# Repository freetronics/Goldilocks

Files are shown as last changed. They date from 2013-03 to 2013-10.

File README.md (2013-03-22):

Freetronics Goldilocks
======================
Copyright 2013 Freetronics Pty Ltd  
Freetronics site:  www.freetronics.com  
Freetronics email: info@freetronics.com  

Add Description

Features:

 * Prototyping area
 * LEDs visible on the edge
 * Mini-USB Connector
 * Overlay guide where you need it (both top and bottom)
 * D13 pin works for everything
 * Mounting holes and power pads
 * All connections in the same place

You can view more online at:

  http://www.freetronics.com/goldilocks

The "docs" folder within this repository includes a handy copy of the
schematic in PDF format, images of the pcb, and our Getting Started
guide that ships with each board.

INSTALLATION
------------
The design is saved as an EAGLE project. EAGLE PCB design software is
available from www.cadsoftusa.com free for non-commercial use. To use
this project download it and place the directory containing these files
into the "eagle" directory on your computer. Then open EAGLE and
navigate to Projects -> eagle -> Goldilocks.

DISTRIBUTION
------------
The specific terms of distribution of this project are governed by the
license referenced below.

LICENSE
-------
Licensed under the TAPR Open Hardware License (www.tapr.org/OHL).
The "license" folder within this repository also contains a copy of
this license in plain text format.

CREDITS
-------
The Eleven was designed Jonathan Oxer (jon@freetronics.com) in
collaboration with Phillip Stevens.

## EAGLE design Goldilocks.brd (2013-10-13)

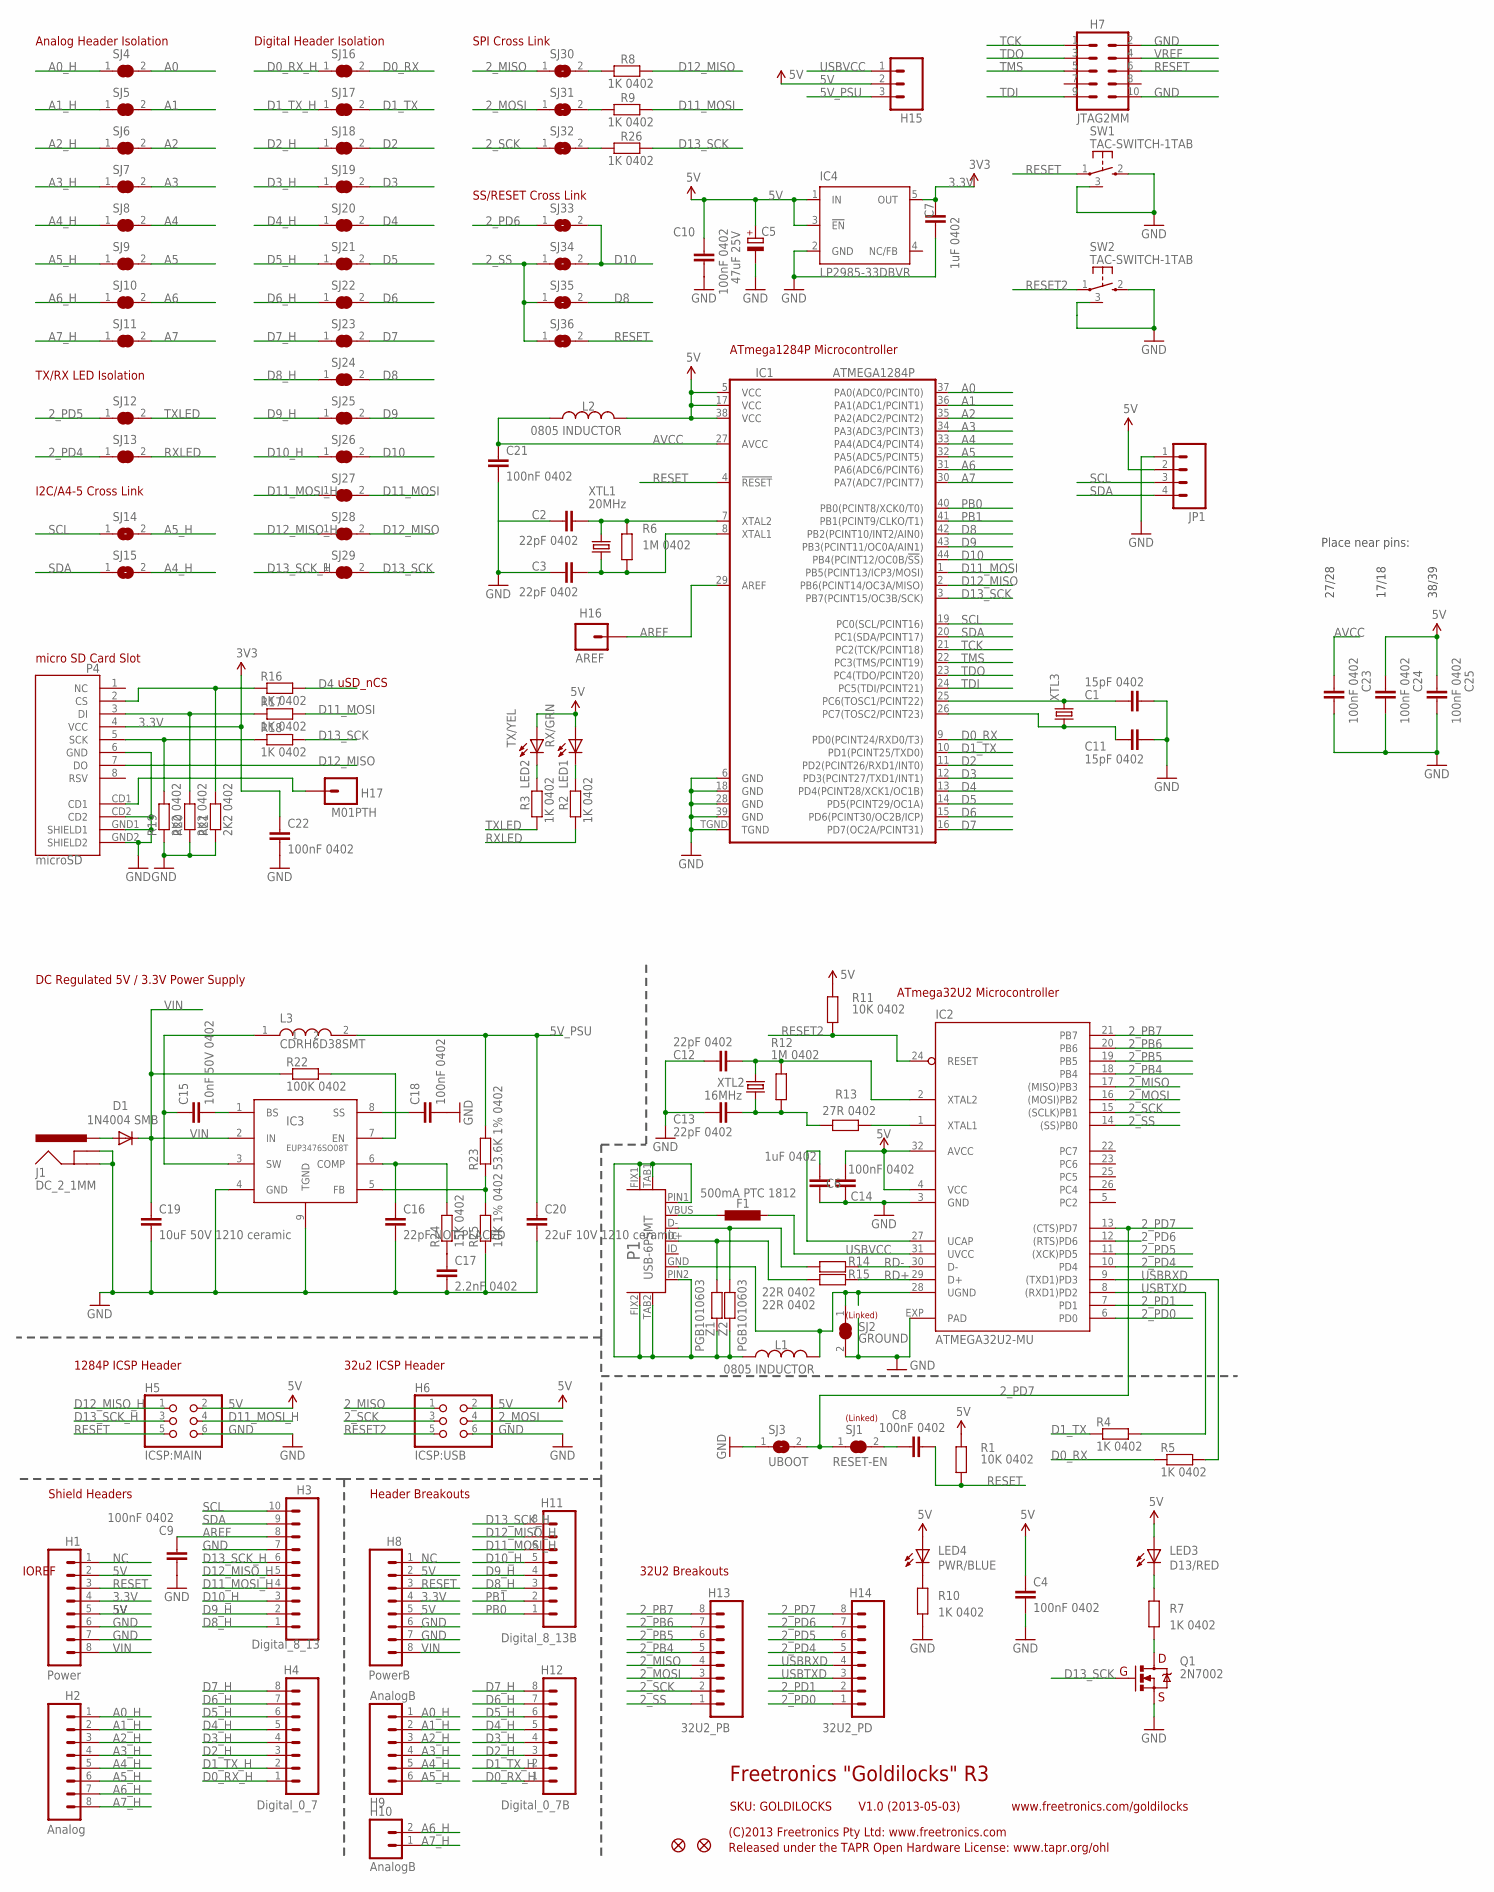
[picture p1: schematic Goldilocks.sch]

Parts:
C1, C11: 15pF 0402; 0402C
C2, C3, C12, C13: 22pF 0402; 0402C
C4, C8, C9, C10, C14, C18, C21, C22, C23, C24, C25: 100nF 0402; 0402C
C5: 47uF 25V; PANASONIC_D
C6, C7: 1uF 0402; 0402C
C15: 10nF 50V 0402; 0402C
C16: 22pF NOT PLACED; 0402C
C17: 2.2nF 0402; 0402C
C19: 10uF 50V 1210 ceramic; C1210
C20: 22uF 10V 1210 ceramic; C1210
D1: 1N4004 SMB; SMB-DIODE
F1: 500mA PTC 1812; L1812
H1: Power; 1X08
H2: Analog; 1X08
H3: Digital_8_13; 1X10
H4: Digital_0_7; 1X08
H5: ICSP:MAIN; 2X03
H6: ICSP:USB; 2X03
H7: JTAG2MM; SAMTEC-TMM-DOUBLE
H8: PowerB; 1X08
H9: AnalogB; 1X06
H10: AnalogB; 1X02
H11: Digital_8_13B; 1X08
H12: Digital_0_7B; 1X08
H13: 32U2_PB; 1X08
H14: 32U2_PD; 1X08
H15: M03PTH; 1X03
H16: AREF; 1X01
H17: M01PTH; 1X01
IC1: ATMEGA1284P; QFN-44M1
IC2: ATMEGA32U2-MU; ATMEL_QFN32
IC3: EUP3476SO08T; SO08T
IC4: LP2985-33DBVR; TEXAS_SOT23-DBV
J1: DC_2_1MM; POWER_JACK_PTH
JP1: M04PTH; 1X04
L1, L2: 0805 INDUCTOR; 0805-LARGE
L3: CDRH6D38SMT; CDRH
LED1: RX/GRN; LED-0402
LED2: TX/YEL; LED-0402
LED3: D13/RED; LED-0402
LED4: PWR/BLUE; LED-0402
P1: USB-6PSMT; USB-MICROB-MB05PMXX
P4: microSD; MICRO-SD-SOCKET-PP
Q1: 2N7002; SOT23-3
R1, R11: 10K 0402; 0402
R2, R3, R4, R5, R7, R8, R9, R10, R16, R17, R18, R26: 1K 0402; 0402
R6, R12: 1M 0402; 0402
R13: 27R 0402; 0402
R14, R15: 22R 0402; 0402
R19, R20, R21: 2K2 0402; 0402
R22: 100K 0402; 0402
R23: 53.6K 1% 0402; 0402
R24: 15K 0402; 0402
R25: 10K 1% 0402; 0402
SJ1: RESET-EN; SJC
SJ2: GROUND; SJC
SJ3: UBOOT; SJ
SJ4, SJ5, SJ6, SJ7, SJ8, SJ9, SJ10, SJ11, SJ12, SJ13, SJ16, SJ17, SJ18, SJ19, SJ20, SJ21, SJ22, SJ23, SJ24, SJ25, SJ26, SJ27, SJ28, SJ29: SJC0402; 0402SJC
SJ14, SJ15: SJ
SJ30: MISO; SJ
SJ31: MOSI; SJ
SJ32: SCK; SJ
SJ33, SJ34, SJ35, SJ36: SJN; SJ
SW1, SW2: TAC-SWITCH-1TAB; TACT-VERT-1TAB
U$5, U$14: FIDUCIAL1X2.5; FIDUCIAL-1X2.5
XTL1: 20MHz; HC49U-V
XTL2: 16MHz; HC49U-V
XTL3: CRYSTALTC38H; TC38H
Z1, Z2: PGB1010603; 0603

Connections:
2_MISO: H6.1, H13.4, IC2.17 ((MISO)PB3), SJ30.1
2_MOSI: H6.4, H13.3, IC2.16 ((MOSI)PB2), SJ31.1
2_PB4: H13.5, IC2.18 (PB4)
2_PB5: H13.6, IC2.19 (PB5)
2_PB6: H13.7, IC2.20 (PB6)
2_PB7: H13.8, IC2.21 (PB7)
2_PD0: H14.1, IC2.6 (PD0)
2_PD1: H14.2, IC2.7 (PD1)
2_PD4: H14.5, IC2.10 (PD4), SJ13.1
2_PD5: H14.6, IC2.11 ((XCK)PD5), SJ12.1
2_PD6: H14.7, IC2.12 ((RTS)PD6), SJ33.1
2_PD7: H14.8, IC2.13 ((CTS)PD7), SJ1.1, SJ3.2
2_SCK: H6.3, H13.2, IC2.15 ((SCLK)PB1), SJ32.1
2_SS: H13.1, IC2.14 ((SS)PB0), SJ34.1, SJ35.1, SJ36.1
3.3V: C7.2, C22.1, H1.4, H8.4, IC4.5 (OUT), P4.4 (VCC)
5V: C4.1, C5.+, C10.1, C14.1, C24.1, C25.1, H1.2, H1.5, H5.2, H6.2, H8.2, H8.5, H15.2, IC1.5 (VCC), IC1.17 (VCC), IC1.38 (VCC), IC2.4 (VCC), IC2.32 (AVCC), IC4.1 (IN), IC4.3 (!EN), JP1.2, L2.2, LED1.A, LED2.A, LED3.A, LED4.A, R1.2, R11.2
5V_PSU: C20.1, H15.3, L3.2, R23.2
A0: IC1.37 (PA0(ADC0/PCINT0)), SJ4.2
A0_H: H2.1, H9.1, SJ4.1
A1: IC1.36 (PA1(ADC1/PCINT1)), SJ5.2
A1_H: H2.2, H9.2, SJ5.1
A2: IC1.35 (PA2(ADC2/PCINT2)), SJ6.2
A2_H: H2.3, H9.3, SJ6.1
A3: IC1.34 (PA3(ADC3/PCINT3)), SJ7.2
A3_H: H2.4, H9.4, SJ7.1
A4: IC1.33 (PA4(ADC4/PCINT4)), SJ8.2
A4_H: H2.5, H9.5, SJ8.1, SJ15.2
A5: IC1.32 (PA5(ADC5/PCINT5)), SJ9.2
A5_H: H2.6, H9.6, SJ9.1, SJ14.2
A6: IC1.31 (PA6(ADC6/PCINT6)), SJ10.2
A6_H: H2.7, H10.2, SJ10.1
A7: IC1.30 (PA7(ADC7/PCINT7)), SJ11.2
A7_H: H2.8, H10.1, SJ11.1
AREF: C9.1, H3.8, H16.1, IC1.29 (AREF)
AVCC: C21.1, C23.1, IC1.27 (AVCC), L2.1
D0_RX: IC1.9 (PD0(PCINT24/RXD0/T3)), R5.1, SJ16.2
D0_RX_H: H4.1, H12.1, SJ16.1
D1_TX: IC1.10 (PD1(PCINT25/TXD0)), R4.1, SJ17.2
D1_TX_H: H4.2, H12.2, SJ17.1
D2: IC1.11 (PD2(PCINT26/RXD1/INT0)), SJ18.2
D2_H: H4.3, H12.3, SJ18.1
D3: IC1.12 (PD3(PCINT27/TXD1/INT1)), SJ19.2
D3_H: H4.4, H12.4, SJ19.1
D4: IC1.13 (PD4(PCINT28/XCK1/OC1B)), R16.2, SJ20.2
D4_H: H4.5, H12.5, SJ20.1
D5: IC1.14 (PD5(PCINT29/OC1A)), SJ21.2
D5_H: H4.6, H12.6, SJ21.1
D6: IC1.15 (PD6(PCINT30/OC2B/ICP)), SJ22.2
D6_H: H4.7, H12.7, SJ22.1
D7: IC1.16 (PD7(OC2A/PCINT31)), SJ23.2
D7_H: H4.8, H12.8, SJ23.1
D8: IC1.42 (PB2(PCINT10/INT2/AIN0)), SJ24.2, SJ35.2
D8_H: H3.1, H11.3, SJ24.1
D9: IC1.43 (PB3(PCINT11/OC0A/AIN1)), SJ25.2
D9_H: H3.2, H11.4, SJ25.1
D10: IC1.44 (PB4(PCINT12/OC0B/!SS!)), SJ26.2, SJ33.2, SJ34.2
D10_H: H3.3, H11.5, SJ26.1
D11_MOSI: H5.4, IC1.1 (PB5(PCINT13/ICP3/MOSI)), R9.2, R17.2, SJ27.2
D11_MOSI_H: H3.4, H11.6, SJ27.1
D12_MISO: H5.1, IC1.2 (PB6(PCINT14/OC3A/MISO)), P4.7 (DO), R8.2, SJ28.2
D12_MISO_H: H3.5, H11.7, SJ28.1
D13_SCK: H5.3, IC1.3 (PB7(PCINT15/OC3B/SCK)), Q1.1 (G), R18.2, R26.2, SJ29.2
D13_SCK_H: H3.6, H11.8, SJ29.1
GND: C1.2, C2.1, C3.1, C4.2, C5.-, C6.2, C7.1, C9.2, C10.2, C11.2, C12.1, C13.1, C14.2, C16.2, C17.2, C18.2, C19.2, C20.2, C21.2, C22.2, C23.2, C24.2, C25.2, H1.6, H1.7, H3.7, H5.6, H6.6, H7.2, H7.10, H8.6, H8.7, IC1.6 (GND), IC1.18 (GND), IC1.28 (GND), IC1.39 (GND), IC1.TGND, IC2.3 (GND), IC2.EXP (PAD), IC3.4 (GND), IC3.9 (TGND), IC4.2 (GND), J1.GND, J1.GNDBREAK, JP1.1, P4.6 (GND), P4.CD2, P4.GND1 (SHIELD1), P4.GND2 (SHIELD2), Q1.2 (S), R10.1, R19.1, R20.1, R21.1, R25.1, SJ2.2, SJ3.1, SW1.2, SW1.3, SW2.2, SW2.3
unnamed: C8.1, SJ1.2
unnamed: IC2.1 (XTAL1), R13.1
unnamed: L1.1, P1.FIX1, P1.FIX2, P1.PIN1, P1.PIN2, P1.TAB1, P1.TAB2, Z1.2, Z2.2
unnamed: LED3.C, R7.2
unnamed: C2.2, IC1.7 (XTAL2), R6.2, XTL1.2
unnamed: Q1.3 (D), R7.1
unnamed: C3.2, IC1.8 (XTAL1), R6.1, XTL1.1
unnamed: D1.A, J1.PWR
unnamed: R8.1, SJ30.2
unnamed: LED1.C, R2.2
unnamed: LED2.C, R3.2
unnamed: LED4.C, R10.2
unnamed: P1.D+, R15.2, Z1.1
unnamed: P1.D-, R14.2, Z2.1
unnamed: C1.1, IC1.25 (PC6(TOSC1/PCINT22)), XTL3.2
unnamed: C11.1, IC1.26 (PC7(TOSC2/PCINT23)), XTL3.1
unnamed: C15.2, IC3.1 (BS)
unnamed: R9.1, SJ31.2
unnamed: C15.1, IC3.3 (SW), L3.1
unnamed: C17.1, R24.1
unnamed: IC3.5 (FB), R23.1, R25.2
unnamed: C18.1, IC3.8 (SS)
unnamed: R26.1, SJ32.2
unnamed: IC3.7 (EN), R22.2
unnamed: C16.1, IC3.6 (COMP), R24.2
unnamed: C12.2, IC2.2 (XTAL2), R12.2, XTL2.2
unnamed: C13.2, R12.1, R13.2, XTL2.1
unnamed: F1.1, P1.VBUS
unnamed: C6.1, IC2.27 (UCAP)
unnamed: P4.2 (CS), R16.1, R21.2
unnamed: P4.3 (DI), R17.1, R20.2
unnamed: P4.5 (SCK), R18.1, R19.2
unnamed: H17.1, P4.CD1
NC: H1.1, H8.1
PB0: H11.1, IC1.40 (PB0(PCINT8/XCK0/T0))
PB1: H11.2, IC1.41 (PB1(PCINT9/CLKO/T1))
RD+: IC2.29 (D+), R15.1
RD-: IC2.30 (D-), R14.1
RESET: C8.2, H1.3, H5.5, H7.6, H8.3, IC1.4 (!RESET), R1.1, SJ36.2, SW1.1
RESET2: H6.5, IC2.24 (RESET), R11.1, SW2.1
RXLED: R2.1, SJ13.2
SCL: H3.10, IC1.19 (PC0(SCL/PCINT16)), JP1.3, SJ14.1
SDA: H3.9, IC1.20 (PC1(SDA/PCINT17)), JP1.4, SJ15.1
TCK: H7.1, IC1.21 (PC2(TCK/PCINT18))
TDI: H7.9, IC1.24 (PC5(TDI/PCINT21))
TDO: H7.3, IC1.23 (PC4(TDO/PCINT20))
TMS: H7.5, IC1.22 (PC3(TMS/PCINT19))
TXLED: R3.1, SJ12.2
UGND: IC2.28 (UGND), L1.2, P1.GND, SJ2.1
USBRXD: H14.4, IC2.9 ((TXD1)PD3), R5.2
USBTXD: H14.3, IC2.8 ((RXD1)PD2), R4.2
USBVCC: F1.2, H15.1, IC2.31 (UVCC)
VIN: C19.1, D1.C, H1.8, H8.8, IC3.2 (IN), R22.1
VREF: H7.4

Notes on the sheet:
DC Regulated 5V / 3.3V Power Supply
ATmega1284P Microcontroller
ATmega32U2 Microcontroller
Freetronics "Goldilocks" R3
V1.0 (2013-05-03)
SKU: GOLDILOCKS
(C)2013 Freetronics Pty Ltd: www.freetronics.com
Released under the TAPR Open Hardware License: www.tapr.org/ohl
www.freetronics.com/goldilocks
(Linked)
IOREF
uSD_nCS
micro SD Card Slot
TX/RX LED Isolation
I2C/A4-5 Cross Link
Digital Header Isolation
Analog Header Isolation
SPI Cross Link
SS/RESET Cross Link
Shield Headers
Header Breakouts
1284P ICSP Header
32u2 ICSP Header
32U2 Breakouts
27/28
17/18
38/39
Place near pins:

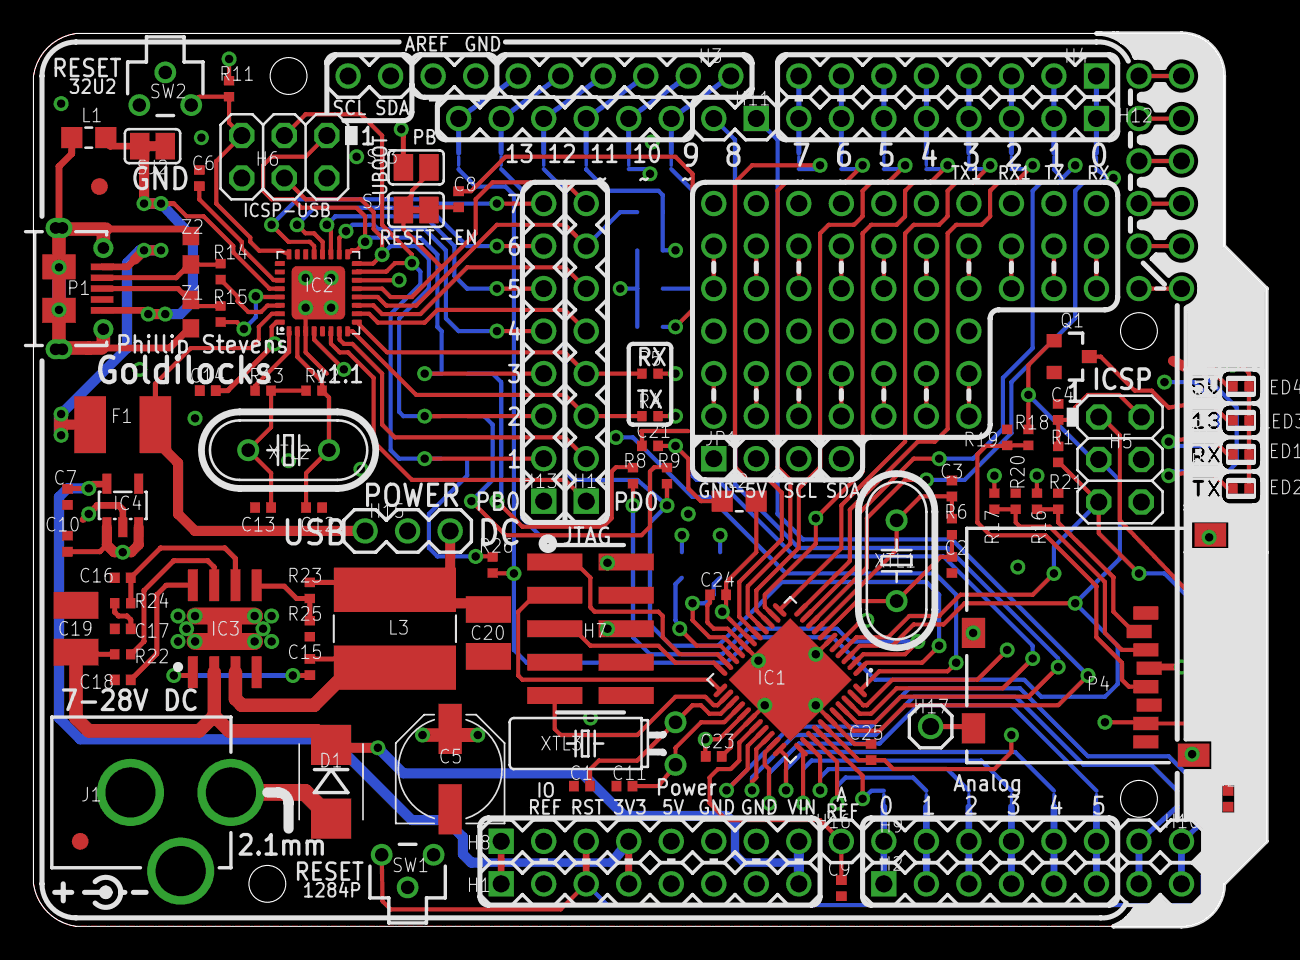
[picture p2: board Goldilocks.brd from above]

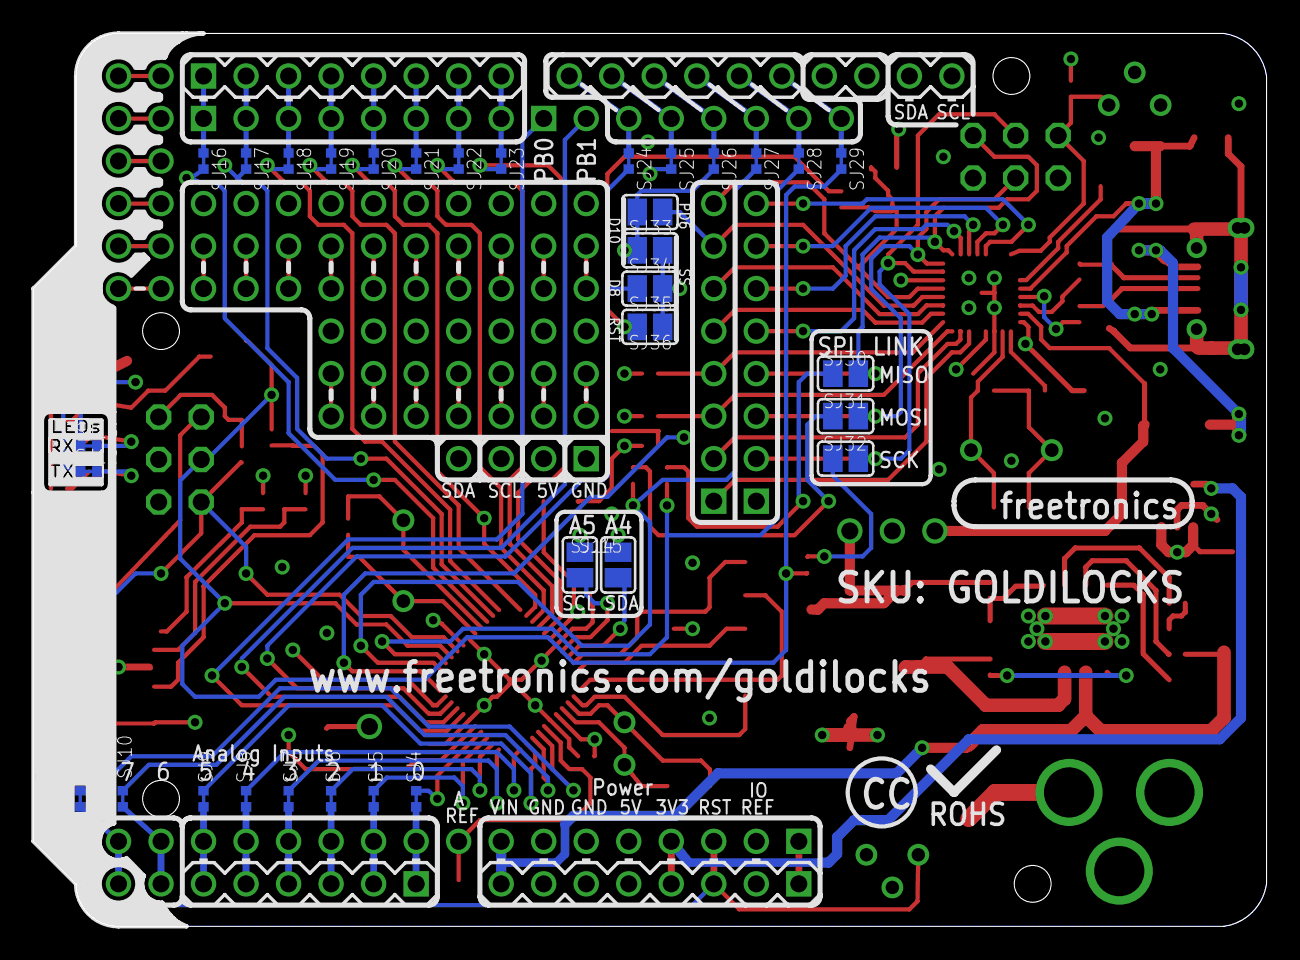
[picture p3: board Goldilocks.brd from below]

Board: 4 copper layers, 73.7 x 53.3 mm, 131 parts (33 on the bottom side), 117 nets.

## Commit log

2013-03-22 Initial project setup
    [Goldilocks.brd, Goldilocks.sch]
2013-05-02 Switched to 4 layer PCB
    [Goldilocks.brd, Goldilocks.sch]
2013-05-03 Hopefully ready for v1.0 release
    [Goldilocks.brd, Goldilocks.sch]
2013-10-13 v1.1 release for production
    [Goldilocks.brd, Goldilocks.sch]

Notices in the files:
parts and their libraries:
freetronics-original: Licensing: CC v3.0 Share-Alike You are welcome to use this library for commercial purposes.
